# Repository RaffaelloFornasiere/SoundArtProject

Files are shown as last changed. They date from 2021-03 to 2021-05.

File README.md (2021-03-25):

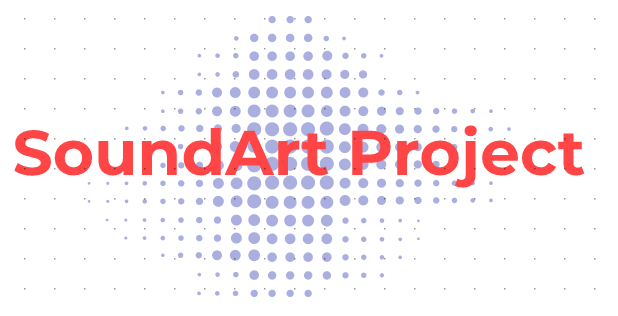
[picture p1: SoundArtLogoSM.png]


# SoundArt Project
#### 
Powered by [Raffaello Fornasiere](https://raffaellofornasiere.github.io/)
### Origin
**SoundArt Project** was born from a Master's thesis on Primary Educations Science. 
The aim is to makes possible to childrens to discover and experience different combination of sounds in realation with their body.
In order to achive this, SoundArt Project provides and extensible system composed by modules that reproduces sounds whenever 
something is posed in front of them. Thanks to multiple devices placed at different places they can move their arms and legs to 
play sounds and different combination of them. 

### Description
The system is composed by indipendend modules capable to detect the presence of a body and reproduce a pre-set sound when the body 
is close enought to the module. All modules are provided by an ultrasonic sensor, that detect the presenco of the body, and a speaker
that reprocudes the setted sound. 
The following features are by now supported (hoping in future additions):
- Setting any .mp3 audio (**basic feature**)
  - (*work in progress*) mulitple file extensions 
- Control the volume of the module (**basic feature**)
- Loop mode: always restart the audio when finished (**basic feature**)
- Web page controlled
- Auto connect to wifi
- (*work in progress*) Setting new wifi
- auto detecting of new modules

### Tecnical details
The systems is based on a server-client architecture, where each module is a client except one that is the server. 
The all modules connects to the same wifi (by now there is the assumption that there is at most one known wifi)
and the user connects to the local page hosted by the server (a DSN is not supported yet, so user can connect to 
the AP provided by the server, connect to the gateway ip and get the ip of the other network).
Once on the page the user have access to all functionalities.

##### Board
The project is developed for the ESP8266 and by now is the only supported uC. 

##### Ultrasonic Sensor
To detect the presence of a body, the HC-SR04 sensor have been used. Since the reproduction of audio 
needs the device not to have long delays, it has been used and async library found [here](https://github.com/jazzycamel/arduino/).

##### ESP8266Audio
In order to reproduce .mp3 files I used [this](https://github.com/earlephilhower/ESP8266Audio) library that perfectly met the needs of the project. 
Thanks to it, each device is able to read an mp3 file from the SD card and then send audio to a PCM5102 through I2S protocol, that will provide 
the input for a class-d amplifier (a generic amp based on tpa3118).

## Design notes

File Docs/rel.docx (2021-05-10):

1. Funzionamento

Il sistema è composto da 5 dispositivi, ognuno in grado di riprodurre un suono ogni volta che rileva un oggetto.

Per ogni dispositivo sono configurabili l’audio da riprodurre, il volume e la possibilità di mettere in loop l’audio.

Quando sono stati salvate queste impostazioni ogni dispositivo lavora in maniera indipendente e riproduce il suono quando rileva un oggetto.

La configurazione viene fatta tramite una pagina web, accessibile tramite un indirizzo IP. Una volta che si ha avuto acesso alla pagina web è possibile gestire le varie tracce audiuo, regolare i volumi dei dispositivi, e impostare la funzionalità loop. Affinchè la configurazione vada a buon fine tutti i dispositvi devono essre collegati alla stessa rete wifi.

  1.1. Architettura del sistema

Il sistema è strutturato seguendo un’architettura client-server: un dispositivo, chiamato server, coordina gli altri dispositivi (client) tramite la rete wifi alla quale sono collegati tutti i dispositivi. Quando viene acceso, il server, invia un messaggio broadcast[^1] in rete e si mette in attesa di ricevere le risposte dagli altri dispositivi collegati.
In questo modo il server è in grado di registrare automaticamente quali sono i dispositivi attivi, per poi creare la pagina web che permette la configurazione.

Ogni configurazione fatta corrisponde ad una richiesta HTTP che viene fatta al server. Ogni richiesta specifica l’argomento della configurazione (volume, audio, loop …) e il dispositivo sulla quale deve essere attuata.
Quindi il messaggio viene innoltrato al dispositivo in questione tramite socket TCP.

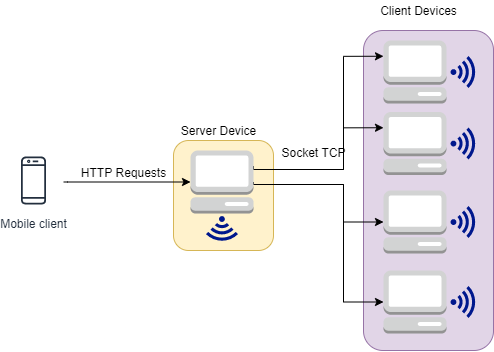
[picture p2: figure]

  1.2. Funzionamento di un singolo dispositivo

Ogni dispositivo è dotato di senosore a ultrasuoni tramire il quale rileva gli oggetti di fronte a esso.

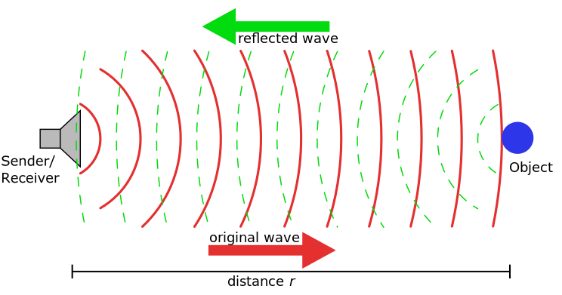
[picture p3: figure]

Il funzionamento sfrutta il tempo di propagazione delle onde ad ultrasuoni (nel caso in esame si tratta di onde a circa 40KHz). Il sensore manda un impulso sonoro che si propaga nel verso in cui è orientato il sensore. Non appena l’onda sonora urta contro un’oggetto, parte di essa rimbalza e ritornerà verso il sensore. In base al tempo che l’onda impiega ad arrivare all’oggetto e a ritornare al sensore, sapendo che la velocità del suono nell’aria è di circa 340m/s è facilmente calcolabile la distanza dell’oggetto.
Ogni dispositivo quindi è in grado di rilevare se vengono posizionati oggetti di fronte ad esso.
In particolare rileva fino a 70cm. Questa limitazione è data dal fatto quando si posizionano più sensori in una stessa area, questi interferiscono tra loro (l’impulso di uno viene ricevuto anche dagli altri). La riduzione della distanza massima rilevabile, assieme alla schermatura del sensore tramite del materiale fonoassorbente permetto a più sensori di lavorare assieme anche se molto vicini tra loro.

2. Progettazione
  2.1. Progettazione Hardware

Il sistema si compone di 3 parti principali: l’elettronica di controllo, i dispositivi per la riproduzione dei suoni ed un telaio che serve sia a contenere l’elettronica sia a fungere da cassa acustica per l’altoparlante.

L’elettronica di controllo è formata da un microprocessore (ESP8266), un convertitore digitale analogico (PCM5102) per la riproduzione audio, il sensore ad ultrasuoni (HC-SR04) per la rilevazione degli oggetti ed una memoria micro-sd, con relativo lettore, per memorizzare alcune informazioni una volta che il dispositivo viene spento. Oltre a coordinare questi ultimi, il microprocessore si occupa di collegarsi al WiFi e di comunicare con gli altri dispositivi.

Per la riproduzione dei suoni si è scelto l’utilizzo di un altoparlante (Dayton Audio PC83-4) e di un amplificatore (TPA3118) che riceve il segnale dal DAC.

La scheda viene alimentata a 24V ed al suo interno presenta un convertitore switching che riduce a 5V. La conversione viene fatta in quanto l’elettronica di controllo deve essere alimentata a 5V mentre l’amplificatore necessita di 24V.

Per contenere tutta l’elettronica è stata progettato un circuito stampato che viene poi inserito in un apposito spazio all’interno del telaio del dispositivo.

Il ruolo principale del telaio è di permettere all’altoparlante di riprodurre i suoni correttamente tramite un carico acustico adeguato. Il dati relativi volume interno e i parametri del condotto reflex sono forniti dall’azienda produttrice degli altoparlanti. Questi dati sono stati poi rielaborati tramite il software WinISD per adeguarli al sistema in questione.

  2.2. Progettazione software

Il Firmware è la parte di codice che comanda l’elettronica di controllo. Per quanto riguarda il server, il firmware si occupa di connetterisi al wifi, rilevare gli altri dispositivi, creare la pagina web, gestire le richieste http, innoltrare le richieste http agli altri dispositivi. I client invece si occupano invece della lettura dei sensori e della riproduzione audio oltre che della connessione al wifi e della ricezione dei messaggi da parte del server.

Il linguaggio utilizzato è il C++ utilizzato il framework fornito per il microprocessore.

Il codice per la pagina web invece è scritto in HTML e JavaScript e si occupa di offrire l’interfaccia grafica all’untente, di inviare le richieste http e di gestire le risposte dal server.

[^1] Messaggio broadcast: un messaggio boradcast viene ricevuto e letto da tutti i dispositivi della rete. Nel caso in questione, il messaggio verrà ricevuto da tutti i dispositivi collegati al wifi al quale sono collegati i sensori.

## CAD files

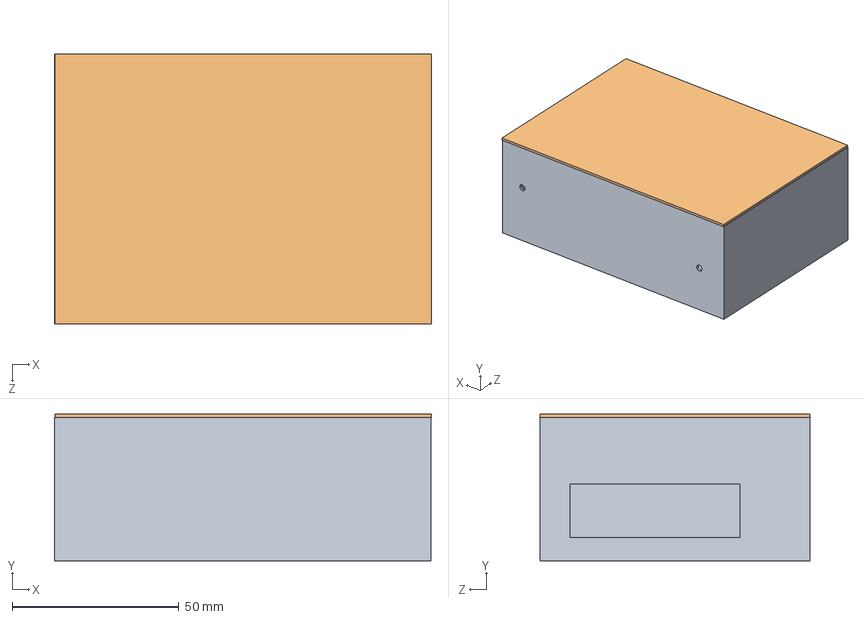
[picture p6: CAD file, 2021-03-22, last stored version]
Audio/Box/SupplyBox/Assem1.SLDASM
113.2 x 44.0 x 81.1 mm
cover

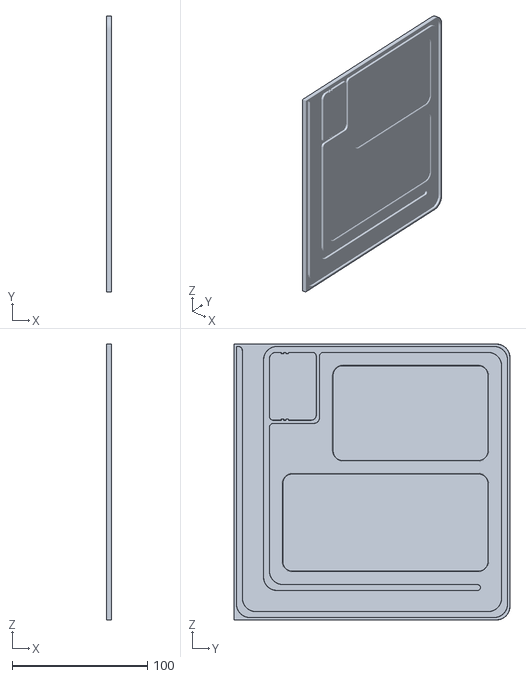
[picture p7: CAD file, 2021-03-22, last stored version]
Audio/Box/3dPrint/simpleV2.STL
4.00 x 204.0 x 204.0

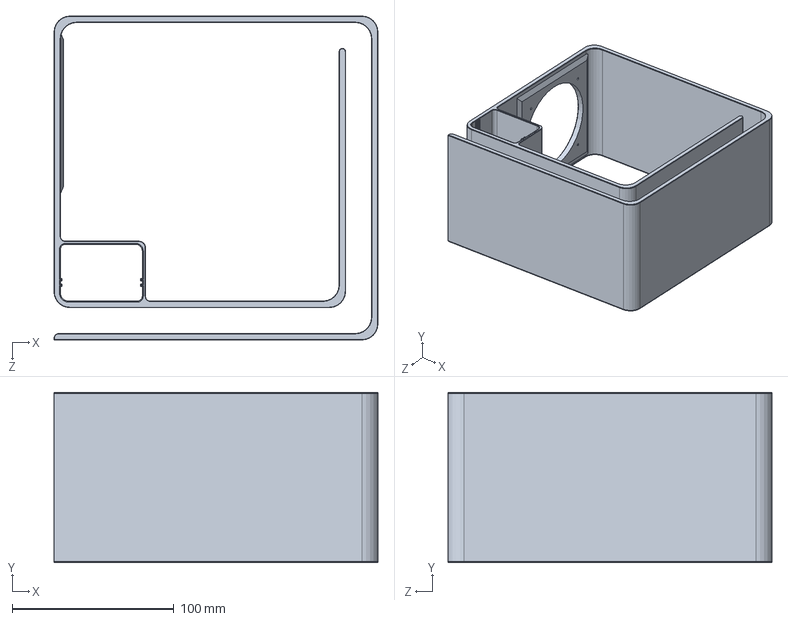
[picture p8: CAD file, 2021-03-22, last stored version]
Audio/Box/interno.SLDPRT
200.0 x 105.0 x 200.0 mm

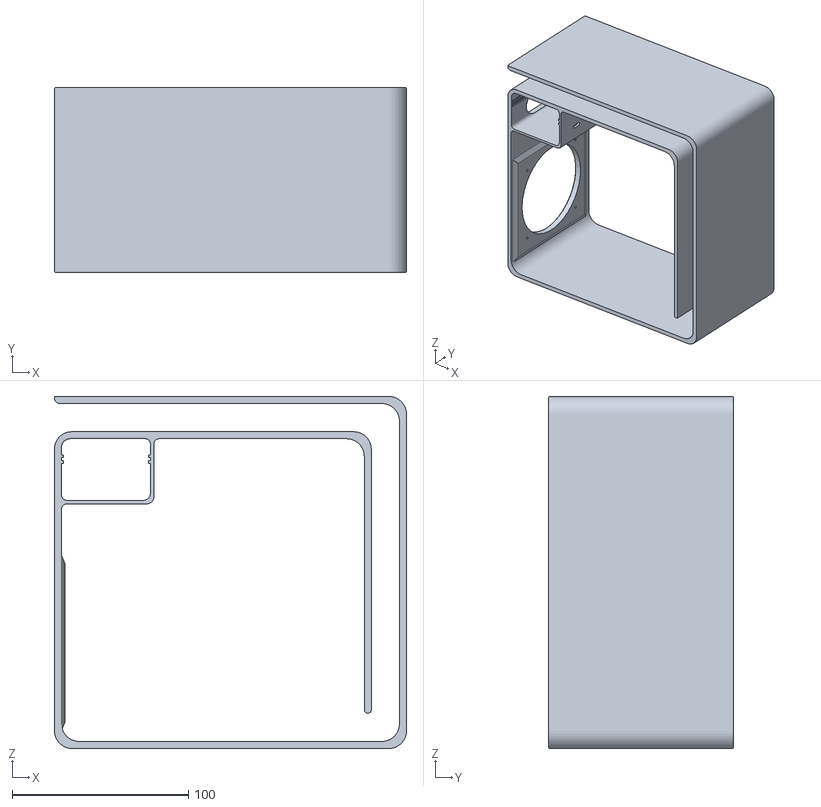
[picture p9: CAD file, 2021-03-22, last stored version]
Audio/Box/3dPrint/internoV2.STL
200.0 x 105.0 x 200.0

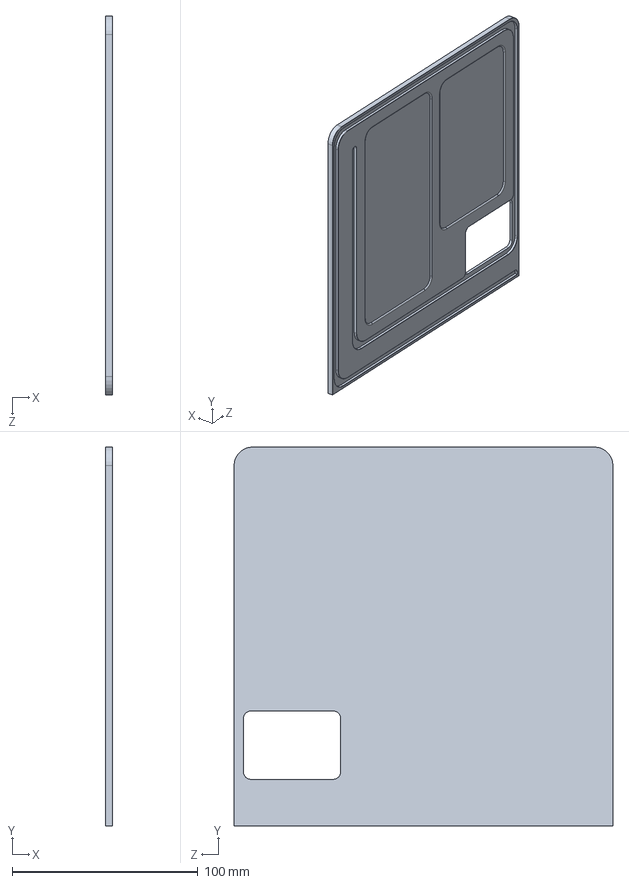
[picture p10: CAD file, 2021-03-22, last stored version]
Audio/Box/simpleFlipped.SLDPRT
4.00 x 204.0 x 204.0 mm

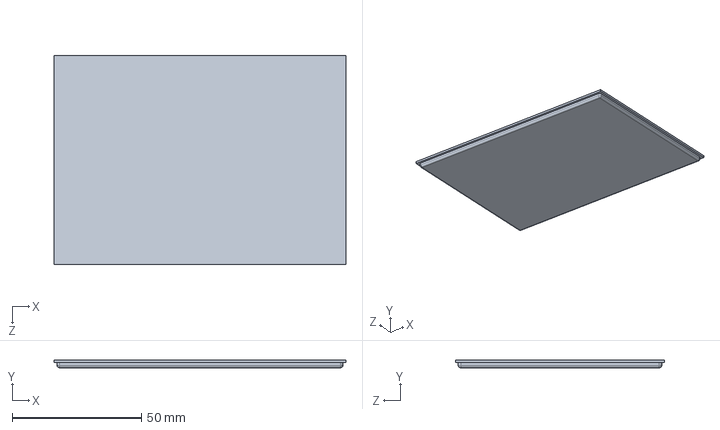
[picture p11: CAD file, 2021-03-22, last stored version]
Audio/Box/SupplyBox/cover.SLDPRT
113.0 x 3.00 x 81.0 mm

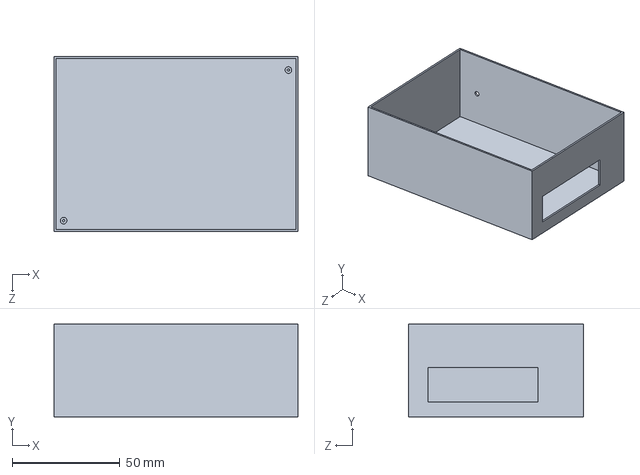
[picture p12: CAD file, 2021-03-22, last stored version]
Audio/Box/SupplyBox/body.SLDPRT
113.0 x 43.0 x 81.0 mm

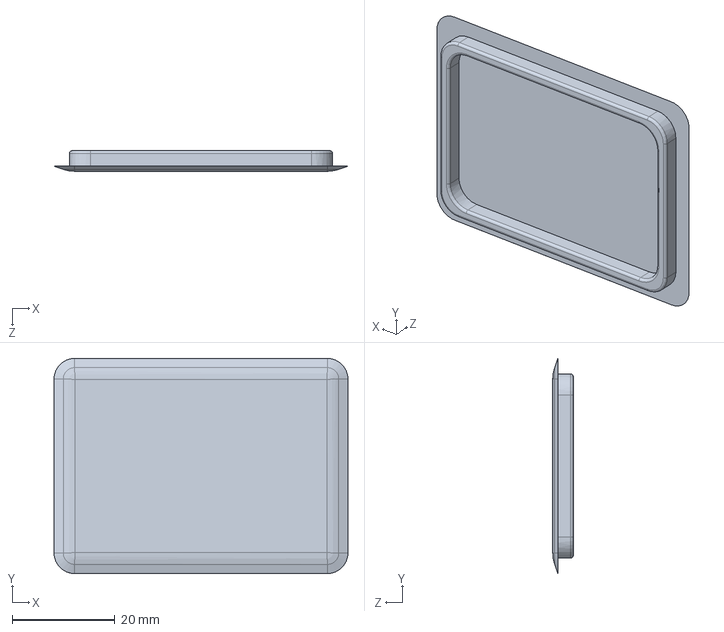
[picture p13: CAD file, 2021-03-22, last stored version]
Audio/Box/tappo.SLDPRT
57.1 x 41.8 x 4.00 mm

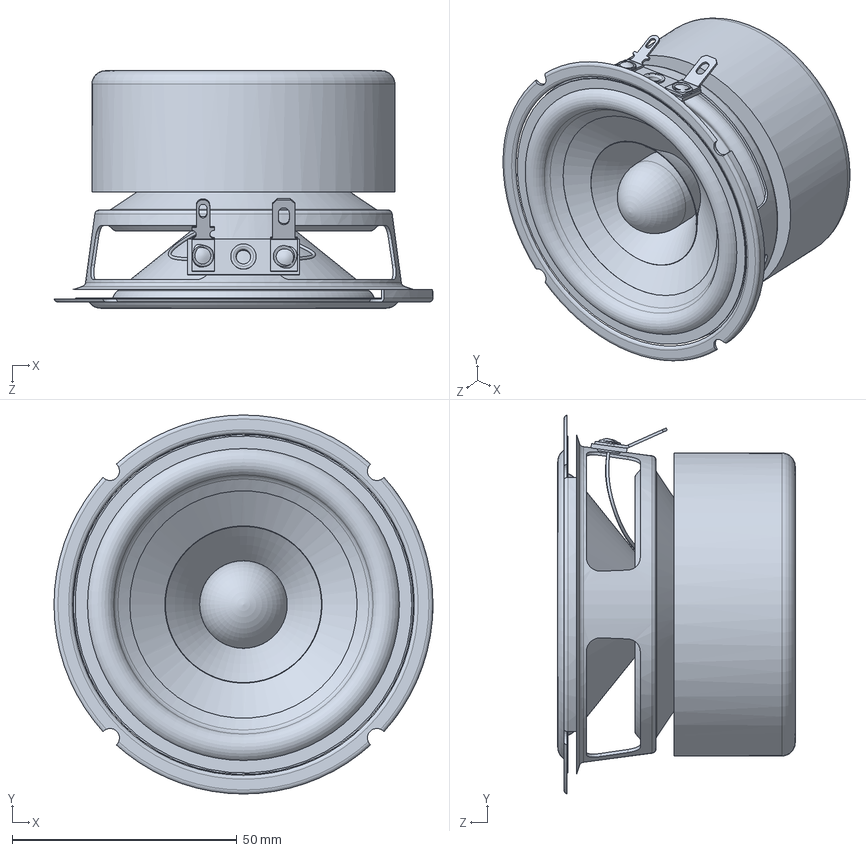
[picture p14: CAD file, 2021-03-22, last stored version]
Audio/Box/Aiyima reproduktor 3Inch širokopásmový středobasový 4Ohm 15W.SLDPRT
84.4 x 84.4 x 52.9 mm

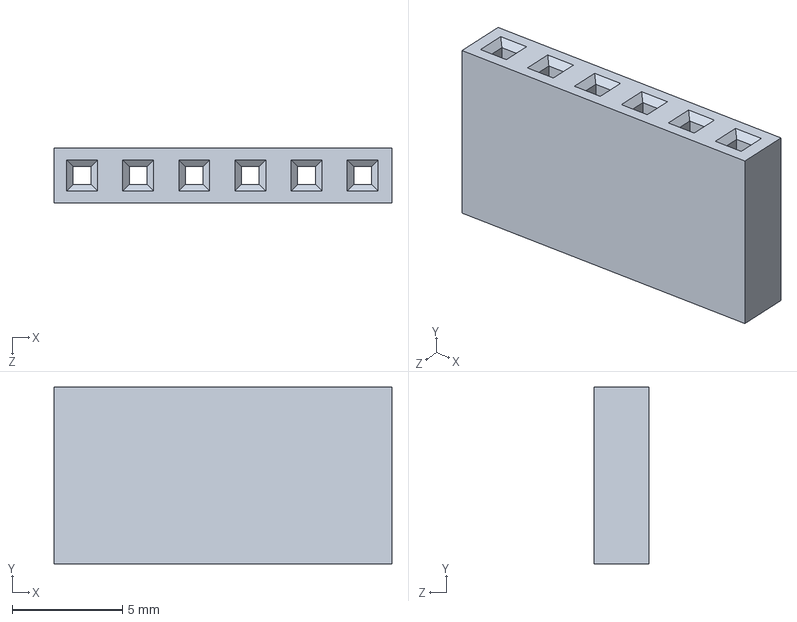
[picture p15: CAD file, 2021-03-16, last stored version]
Audio/Box/Header_Female_Single_6.SLDPRT
15.3 x 8.00 x 2.50 mm

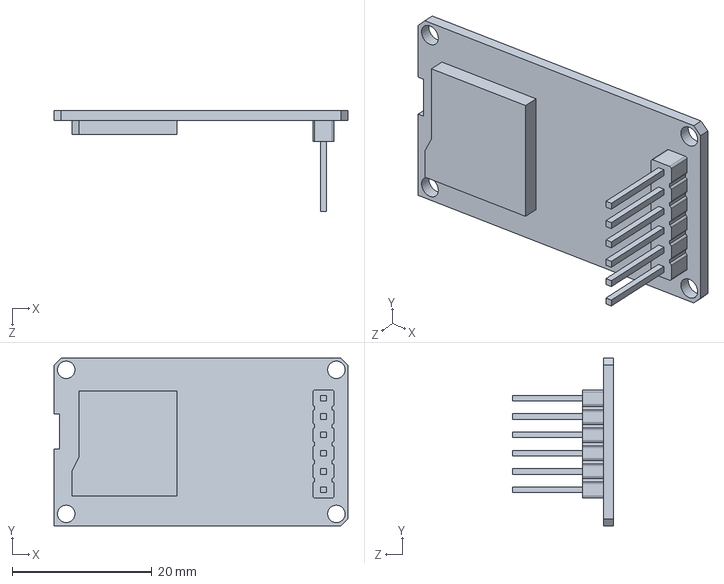
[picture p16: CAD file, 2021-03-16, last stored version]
Audio/Box/sdreader.SLDPRT
42.0 x 24.0 x 14.4 mm

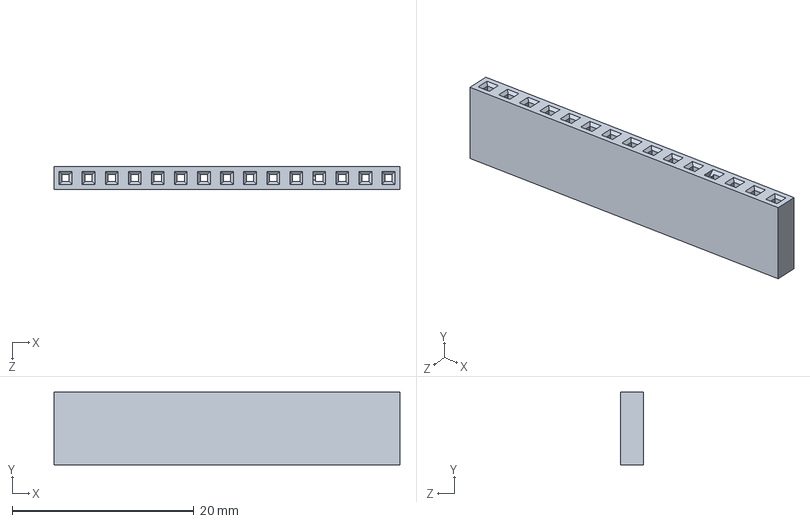
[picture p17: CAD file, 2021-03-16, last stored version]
Audio/Box/Header_Female_Single_15.SLDPRT
38.1 x 8.00 x 2.50 mm

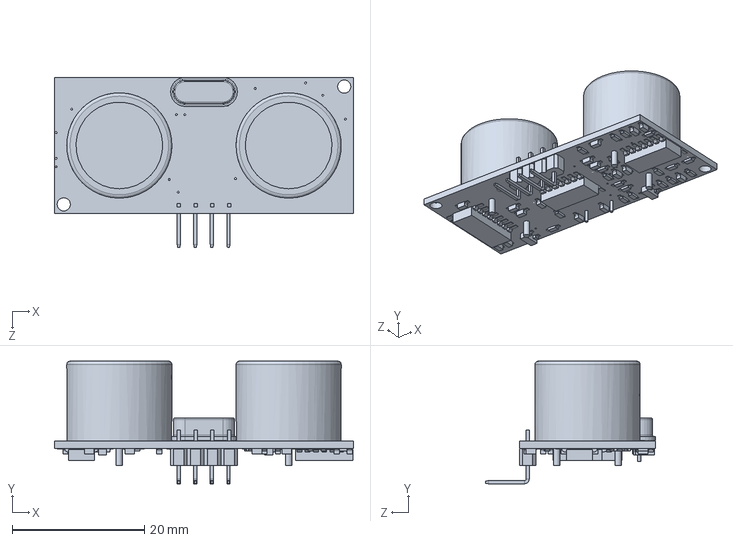
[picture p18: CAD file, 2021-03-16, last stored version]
Audio/Box/hc-sr04.SLDPRT
45.2 x 18.5 x 25.8 mm

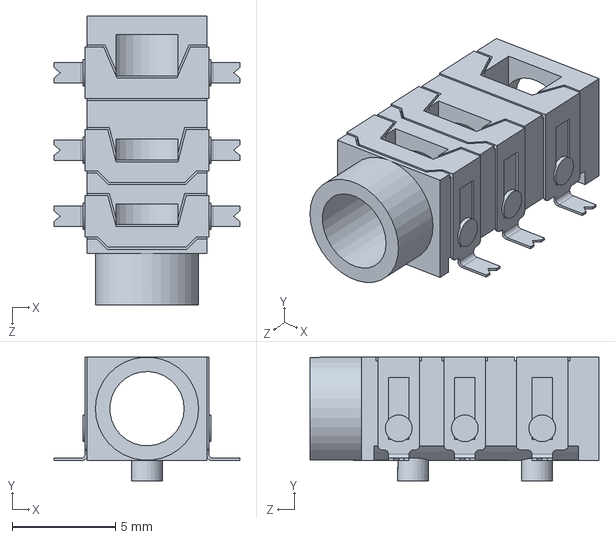
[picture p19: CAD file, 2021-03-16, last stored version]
Audio/Box/JackPJ313D.SLDPRT
9.00 x 6.00 x 14.0 mm

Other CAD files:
Audio/Box/3dPrint/simpleFlippedV2.STL
Audio/Box/simple.SLDPRT
Audio/Box/CONECTOR_DC.SLDPRT
Audio/Box/scheda.SLDPRT
Audio/Box/3dPrint/interno.STL
Audio/Box/3dPrint/simple.STL
Audio/Box/3dPrint/simpleFlipped.STL
Audio/Box/M2x10 countersunk.SLDPRT
Audio/Box/interno.STL
Audio/Box/simpleFlipped.STL

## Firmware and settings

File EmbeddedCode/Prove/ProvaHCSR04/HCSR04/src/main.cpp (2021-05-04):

#include <Arduino.h>
#include <HC_SR04.h>
#include <math.h>

HC_SR04 hc(D3, D1);

void setup()
{
  Serial.begin(500000);
  hc.begin();
  hc.start();
}



String intToFormattedString(int n, int f)
{
  String res;
  for (int i = 0; i < f - log10(float(n)); i++)
    res += " ";
  res += String(n);
  return res;
}


int detectedDist;
int distance = 30;
unsigned long int debounceT = 100;

void loop()
{
  static int size = 40;
  static std::vector<int> values(size, 0);
  static int index = 0;
  static int oldVal = 0;
  static long unsigned t = millis();
  static bool objDetected = false;
  static bool auxDetect = false;

  if (hc.isFinished())
  {
    values[index] = hc.getRange();
    detectedDist = 0;
    for(int i = 0; i < size; i++)
      detectedDist += values[i];
    detectedDist /= size;
    //Serial.println(" ------ Distance computed: " + String(detectedDist) + " index: " + String(index));
    if (++index >= size)
      index = 0;
    oldVal = values[index];
    hc.start();
  }

  if((detectedDist < distance) != objDetected)
    {
        if(!auxDetect)
            t = millis();
        auxDetect = true;
    }
    else 
        auxDetect = false;

    if(auxDetect && ((millis() - t) > debounceT))
    {
        objDetected = !objDetected;
        Serial.println(objDetected?"detected":"non detected");
    }
}

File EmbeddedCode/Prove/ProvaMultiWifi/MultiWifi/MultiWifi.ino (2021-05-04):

#include "ESP8266WiFi.h"

#include <ESP8266WiFi.h>        // Include the Wi-Fi library

const char* ssid     = "TP-Link_739F";         // The SSID (name) of the Wi-Fi network you want to connect to
const char* password = "32527476";     // The password of the Wi-Fi network


void setup()
{
  Serial.begin(115200);
  Serial.println("");

  WiFi.mode(WIFI_STA);
  WiFi.disconnect();
  delay(100);
  Serial.print("Scan start ... ");
  int n = WiFi.scanNetworks();
  Serial.print(n);
  Serial.println(" network(s) found");
  for (int i = 0; i < n; i++)
  {
    Serial.println(WiFi.SSID(i));
  }
  Serial.println();

  delay(1000);
   Serial.println();
   Serial.print("MAC: ");
   Serial.println(WiFi.macAddress());

     
  WiFi.begin(ssid, password);             // Connect to the network
  Serial.print("Connecting to ");
  Serial.print(ssid); Serial.println(" ...");

  int i = 0;
  while (WiFi.status() != WL_CONNECTED) { // Wait for the Wi-Fi to connect
    delay(1000);
    Serial.print(++i); Serial.print(' ');
  }

  Serial.println('\n');
  Serial.println("Connection established!");  
  Serial.print("IP address:\t");
  Serial.println(WiFi.localIP());         // Send the IP address of the ESP8266 to the computer
}

void loop()
{
  
}

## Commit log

2021-03-16 all tests work fine
    [Aiyima reproduktor 3Inch širokopásmový středobasový 4Ohm 15W.SLDPRT, CONECTOR_DC.SLDPRT, Header_Female_Single_15.SLDPRT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]
2021-03-22 auto connection working
    [Aiyima reproduktor 3Inch širokopásmový středobasový 4Ohm 15W.SLDPRT, Assem1.SLDASM, Costo.xlsx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]
2021-03-22 auto connect working
    [Assem1.SLDASM, body.SLDPRT, cover.SLDPRT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]
2021-03-25 fixing fileTransferManager and unifying library dir
    [main.cpp]
2021-03-25 test removing
    [Aiyima reproduktor 3Inch širokopásmový středobasový 4Ohm 15W.SLDPRT, Assem1.SLDASM, CONECTOR_DC.SLDPRT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]
2021-03-25 removing useless files
    [Costo.xlsx]
2021-05-04 Added SensorsDiagram
